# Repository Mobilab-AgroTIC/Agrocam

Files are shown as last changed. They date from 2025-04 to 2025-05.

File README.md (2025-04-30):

# Agrocam
L’Agrocam est un objet connecté à construire soi-même permettant de prendre des photo quotidiennement.

Ce système a été testé dans divers contextes, notamment pour suivre la croissance de la vigne, les opérations qui y sont menées (rognage, travail du sol, épamprage) … Des caméras sont maintenant aussi déployées sur d'autres cultures par des membres de la communauté en grande culture.

[Ce tutoriel](https://mobilab.agrotic.org/2025/02/18/agrocam/) vous guidera dans la fabrication d’une Agrocam. Le système est connecté via le réseau 3G/4G, ce qui permet de visualiser les photos directement sur Internet, avec une remontée tous les jours.

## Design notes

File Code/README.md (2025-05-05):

**Ce readme n'est plus maintenu à jour, pour suivre le tutoriel aller sur https://mobilab.agrotic.org/2025/02/18/agrocam/**
Ce Readme vous accompagne sur les étapes à accomplir pour paramétrer le Raspberry et la carte Witty Pi 4. 

Vous devriez avoir le matériel suivant : 



Pour commencez ce tutoriel et si vous souhaitez envoyer vos images sur agrocam.agroti.org afin de les visualiser vous devez déclarer votre Agrocam. Pour l'instant, il n'y a pas de procédure automatisée pour la déclaration de votre Agrocam. Il faudra donc envoyer un mail à basile.ploteau@supagro.fr en indiquant que vous souhaitez créer une Agrocam. Il vous renverra une chaine de 8 caractères qui sera le nom de votre Agrocam ainsi que le fichiers credentials.py utile dans la suite du tutoriel. Il faudra conserver ce nom car il sera utile à différents moments du tutoriel.

Ce Readme vous accompagne sur les étapes à accomplir pour paramétrer le Raspberry et l'Arduino promini 3,3 V. Le tutoriel est découpé en 3 grandes étapes : 

# 1. Préparer le dongle 4G
## 1.1. La carte SIM
Pour fonctionner de manière connectée l'Agrocam a besoin de connexion Wifi. Dans ce tutoriel vous suiverez des étapes qui permettent d'intégrer une clé 4G dans l'Agrocam qui produit directement un réseau Wifi. Pour fonctionner, cette clé 4G a besoin d'une carte SIM (les mêmes qu'il y a dans les téléphones). Un forfait de 5 Go/mois sera largement suffisant pour envoyer une photo par jour, il existe maintenant des forfaits abordables. Vous pouvez choisir de passer par n'importe quel opérateurs. Jusqu'à maintenant l'Agrocam a été testée avec les réseaux de Orange et de Bouygues.

## 1.2. Paramétrer le dongle 4G
Avant d'insérer la carte SIM dans le Dongle 4G, assurez vous d'avoir supprimé le code PIN. Pour retirer le code PIN de la carte SIM il faut insérer la carte dans un téléphone et se rendre dans les paramètres de ce dernier pour désactiver la sécurité.

Vous pouvez essayer d'insérer la carte SIM dans le Dongle 4G et de brancher la clé 4G à une alimentation USB. Ensuite connectez vous à votre clé 4G en wifi avec un ordinateur ou un smartphone (le nom de la clé (son SSID) et son mot de passe d'usine (souvent : "1234567890" sont indiqués sur le dos de la clé 4G). 
Vous devriez avoir accès à internet, faite une recherche sur Google pour vérifier que c'est bien le cas. Si tout fonctionne vous pouvez passer à la partie 2. Il est possible que malgré une carte SIM fonctionnelle la connection à internet ne se fasse pas. Cela est du à un problème d'APN mal configuré sur la clé 4G.
Pour modifier les paramètres d'APN vous devrez :

**3. Réaliser le montage électronique**

# 1. Programmer l'Agrocam 
## 1.1. Paramétrer le dongle 4G
Avant d'insérer la carte SIM dans le Dongle 4G, assurez vous d'avoir supprimer le code PIN. Pour retirer le code PIN de la carte SIM il faut insérer la carte dans un téléphone et se rendre dans les paramètres de ce dernier pour désactiver la sécurité.

- Vous connecter au réseau Wifi du dongle 4G avec votre PC
- Vous connecter à l'interface de paramétrage du dongle. Pour cela vous devez taper dans un navigateur quelconque l'adresse IP locale de votre Dongle. Elle est souvent indiquée au dos du Dongle et ressembe à quelque chose comme : 192.168.100.1
- Le dongle vous demande des identifiants, par défaut Username : "admin" et Password : "admin"



- Une fois connecté vous pouvez aller dans Advanced>APN Setting



- Vous cochez "profile 1" à la place de "default". Ensuite le remplissage du formulaire dépend de chaque opérateur. En général chez Orange il n'y a qu'un seul APN donc rarement des problèmes mais chez leur concurents il faut souvent tester différents APN. Voici les paramètres qui ont fonctionné pour une carte SIM Bouygues. Attention l'APN peut différer en fonction du forfait que vous avez pris.



- Une fois le formulaire créé cliquez sur "Save Configuration" puis "Execute"
- Attendez quelques secondes, ouvrez un nouvel onglet et faite une recherche pour vérifier si vous êtes bien connecté.

# 2. Préparer le Raspberry Pi Zero 
## 2.1. Initialiser le Raspberry Pi Zero
- Installer Raspberry Pi imager https://www.raspberrypi.com/software/
- Ouvrir Raspberry Pi imager
- Insérer la carte SD du raspberry dans le PC
- La fenêtre suivante s'affiche. Il faut passer dans les 3 menus pour préparer l'écriture de l'image sur le raspberry


1. Sélectionner le modèle du Raspberry **Raspberry pi zero**
2. Sélectionner l'OS **Raspberry Pi OS Lite (32-bit)**
3. Sélectionner l'espace de stockage correspondant à la carte SD

- Puis en cliquant sur **Suivant** un message demande si vous souhaitez modifier les paramètres. Cliquez sur **Modifier réglages**, une fenêtre s'ouvre:



- **Dans General** : Vous pouvez indiquer un nom d'utilisateur et un mot de passe pour votre Raspberry, vous pouvez conserver "pi" pour les deux. Vous pouvez aussi donner comme mot de passe la chaine de 8 caractères qui vous a été attribué lors de la déclaration de l'Agrocam sur le serveur, cela sécurisera votre raspberry s'il devait tomber entre de mauvaises mains.
- **Dans General** : Définir les paramètres Wifi (SSID, Password, pays (FR)) du dongle 4G. Bien penser à vérifier que le "pays Wifi" est en "FR"
- **Dans Service** : Activez le SSH et sélectionnez "utiliser un mot de passe pour l'authentification"



4. Cliquez sur **enregistrer** puis sur **Oui** puis une dernière fois sur **Oui**
5. L'écriture peut prendre du temps, n'hésitez pas à faire les installations de la partie 2.3 en attendant

## 2.2. Installer les logiciels pour la suite
- Installer [WinSCP](https://winscp.net/eng/download.php) sur votre PC. Ce logiciel permet de se connecter au raspberry en SSH, de parcourir ses fichier et d'interagir avec le terminal de commandes.
- Installer [Network analyzer](https://play.google.com/store/apps/details?id=net.techet.netanalyzerlite.an&hl=fr&gl=US) sur votre smartphone. Cette application permet de scaner un réseau wifi et de trouver les appareils (leur adresse IP) qui y sont connectés.

## 2.3. Réaliser les branchements
- Insérer la carte SD dans le raspberry
- Brancher la Picam. Attention au sens de branchement de la nappe de cable _(cf. photo ci-dessous)_. Attention les connecteurs sont fragiles, à manipuler avec précautions.


- Brancher le dongle 4G au Raspberry sur le port **"USB"** _cf. photo ci-dessous_ _Par la suite il est possible que le dongle se déconnecte de temps à autre, ce qui va poser problème. Cela est du au Raspberry qui en fonction des modèle de dongle 4G ne fournit pas une intensité suffisante. Si cela se présente, veuillez brancher le dongle sur une autre source de courant par exemple un chargeur rapide 2 ampères de téléphone portable_
- Brancher l'alimentation sur le port **"PWR IN"** _cf. photo ci-dessous_


## 2.4. Se connecter au Raspberry depuis un PC

- Connecter un smartphone au réseau du dongle 4G (avec SSID et mot de passe précédemment paramétrés)
- Avec l'application mobile Network Analyzer cliquer sur "Scan" et identifier l'adresse IP du raspberry Pi:


- Sur PC, ouvrir WinSCP et créer une nouvelle session de connexion au Raspberry . Saisir les informations suivantes : Protocole de fichier : **SFTP**; Nom d'hôte : **IP obtenue sur Network analyzer**; Nom d'utilisateur : **pi** (sauf changement); Mot de passe : **défini partie 2**
- Depuis WinSCP ouvrir Putty 
- Un terminal de commande s'ouvre et vous demande un mot de passe. Il s'agit toujours du même défini à la partie 2. Le mot de passe ne s'affiche pas mais appuyer sur "entrée" et ça marche. Attention, le Ctrl+V ne fonctionne pas sur le terminal de commande. Si vous souhaitez coller quelque chose, il faudra simplement faire un clic droit.

## 2.5. Installer les librairies 

```
sudo apt install python3-smbus
sudo apt install python3-picamera2
```
Par moment l'installation s'arrête pour vous demander si vous souhaitez continuer. Tapez "Y" puis "entrée" et l'installation continue.

## 2.6 Ajouter d'autres SSID (optionnel)
Pour l'instant vous ne pouvez accéder à votre raspberry qu'en vous connectant en SSH par l'intermédiaire du Dongle 4G. Cela est risqué car si le dongle ne fonctionne plus, vous ne pourrez plus accéder au raspberry. On vous recommande donc d'ajouter d'autres SSID (votre partage de connexion par exemple. Pour cela :
- ```nmcli device wifi list``` permet de visualiser les SSID disponibles
- ```nmcli device wifi connect "SSID" password "PASSWORD"```
- Attention lorsque le raspberry a réussi à se connecter à un autre wifi, votre terminal putty ne communique plus avec le raspberry car votre PC et le raspberry ne sont plus sur le même réseau. 
  
# 3 Ajouter les fichiers sur le raspberry pi
### 1.6.2 Installer WiringPi
```
git clone https://github.com/WiringPi/WiringPi.git
cd WiringPi
git pull origin
./build
cd ..
```
### 1.6.3 Installer pip et python-dotenv
Cela peut prendre un peu de temps 
```
sudo apt-get install python3-pip
pip install python-dotenv
sudo cp -R /home/pi/.local/lib/python3.9/site-packages/dotenv /usr/lib/python3.9 
```
*On déplace la librairie pour qu'elle soit trouvée en démarrage automatique*
## 1.7. Ajouter les fichiers sur le raspberry pi
Cette opération peut se faire depuis WinSCP en glissant et déposant les fichiers
## 3.1 Créer le répertoire pour les photo
```
sudo mkdir Agrocam
```
## 3.2 Choisir votre fréquence d'allumage
Vous avez normalement reçu un fichier "credentials.py" de la part de Basile Ploteau lorsque vous avez demandez la création de votre Agrocam. Ouvrez ce fichier avec n'importe quel editeur de text comme Notepad++ ou un simple bloc note. Il y a une liste qui s'appelle ```trigger_times``` et qui contient les heures (GMT) à laquelle vous souhaitez que l'Agrocam se déclenche. Par exemple ```trigger_times=[time(6,30,00),time(8,40,00),time(12,0,0)]``` déclenchera une acquisition de photo à 6:30:00, 8:40:00 et 12:00:00; ```trigger_times=[time(12,0,0)]``` déclenchera une acquisition de photo à 12:00:00.

## 3.3 Ajouter les fichiers
Depuis l'interface de WinSCP déplasser les fichiers suivants. Le fichier agrocam.py se trouve sur ce repertoire Github. Le fichier credentials.py vous a été envoyé par Basile Ploteau.
- Glisser déposer agrocam.py dans /home/pi
- Glisser déposer credentials.py dans /home/pi
Donner tous les droits au script _(première ligne ci-dessous)_ et effacer les "\r" et "r" de fin de ligne _(2e ligne ci-dessous, cela n'est pas toujours nécessaire mais ces caractère spéciaux on pu être ajouté si le script a été édité sur un outil Windows, Visual Studio Code par exemple)_
```
sudo chmod 777 Agrocam
sed -i -e 's/\r$//' agrocam.py
sed -i -e 's/\r$//' credentials.py
```
**NB :** Le script agrocam.py envoie la commande ```sudo shutdown -h now``` à la fin de son exécution ce qui éteint l'Agrocam. Pour débugger le script (c'est-à-dire reprendre la main dessus) il est recommandé de commenter cette ligne _cf. partie 7_

# 4. Programmer l'allumage de l'Agrocam avec la carte WittyPi
## 4.1 Installer WittyPi
Installer WittyPi avec les lignes de commandes suivantes.
```
wget http://www.uugear.com/repo/WittyPi4/install.sh
sudo sh install.sh
```
Puis éteindre le raspberry avec ```sudo shutdown -h now```. Attendre que la LED verte s'eteigne définitivement puis débrancher l'alimentation électrique. 

## 4.2 Connecter la carte WittyPi 4 au Raspberry
Insérer une pile 3V (si possible rechargeable et fourni avec la carte WittyPi 3) dans l'emplacement prévu à cette effet sur la carte Witty Pi

Les broches s'emboitent de la manière suivante.



## 4.3 Paramétrer le WittyPi
Brancher l'alimentation électrique directement sur la carte Witty Pi 4 (l'alimentation du raspberry a été débranché en 4.1), c'est cette carte qui va ensuite gérer l'alimentation du raspberry. Pour que le raspberry démarre (en attendant qu'on lui donne un planing de mise en route), il faut appuyer sur le bouton poussoir de la carte Witty Pi. Lors de cette première mise en route, il est possible que le Dongle 4G ne s'allume pas. Il suffit de le débrancher et rebrancher.



Se connecter au Raspberry comme dans la partie 2.4, ouvrir le terminal de commande et démarrer WittyPi avec la commande suivante :
Depuis WinSCP, glisser déposer .env dans ```/home/pi``` une fois modifié avec les informations pertinentes entre les "" (hostname,user,password). Ce fichier contient les informations d'authentification pour accéder au serveur FTP sur lequel les photos seront sauvegardées. Attention le fichier peut être caché

Le fichier peut aussi être crée depuis le terminal :
```
touch .env
sudo nano .env
```
Contenu de .env
```
hostname = ""
user = ""
password =""
```

## 1.8. Démarrer la script au reboot
Cette partie permet de démarrer le script ```Agrocam_raspberry.sh``` au démarrage. Attention, le script éteint le raspberry à la fin de son exécution. Cette extinction n'a pas lieu si ```controlPin==1```, il faut donc brancher le GPIO 24 au 3,3v pour que l'Agrocam reste allumée _cf. partie 1.10._

Ouvrir le crontab 
```
sudo crontab -e
```
Puis sélectionner ```1. /bin/nano``` en tapant ```1```
Ajouter une ligne à la fin du crontab :
```
@reboot sudo /home/pi/Agrocam_raspberry.sh 
```
Ajouter ```>> /var/log/Agrocam.log 2>&1``` à la ligne précédente pour créer un fichier de log pour débugger

## 1.9. Tester le script
Pour relancer le raspberry : ```sudo reboot```, il devrait s'allumer, actionner le servomoteur, prendre une photo, réactionner le servomoteur, envoyer la photo sur le serveur et enfin s'éteindre.

## 1.10. Debugger l'Agrocam
Le script ```Agrocam_raspberry.sh``` éteint l'Agrocam à la fin de son exécution, une fois cette partie 1 terminée il serait donc impossible de se connecter au raspberry en SSH car le script ```Agrocam_raspberry.sh``` est lancé à chaque démarrage _(cf. partie 1.8)_. La solution consiste donc à empêcher que le script n'aille jusqu'au bout lorsqu'on le désire. Pour celà il y a une boucle en python à la fin du script qui tourne indéfiniement si le port GPIO 24 est "TRUE" donc connecté au 3,3V **(à l'aide du cavalier)**:
```
import time
import RPi.GPIO as GPIO
controlPin=24
GPIO.setmode(GPIO.BCM)
GPIO.setup(controlPin, GPIO.IN)
i=1
while (GPIO.input(controlPin) == 1) :
	time.sleep(5)
	print("ControlPin is not LOW. i = ", i)
	i += 1
```

# 2. Programmer l'allumage de l'Agrocam
On va se servir d'un arduino mini pour alimenter le Raspberry à intervalles régulier (et donc prendre une photo). L'arduino active un transistor qui lui même connecte le raspberry à une power bank _(cf. schéma en partie 3)_ 
- Installer le logiciel [Arduino](https://www.arduino.cc/en/software)
## 2.1 Brancher l'Arduino au PC
- Utiliser un FTDI pour relier l'Arduino mini au PC. S'il s'agit d'un Arduino mini 3,3 V penser à ce que le FTDI soit sur la position 3,3V (boutou ou cavalier selon les modèles)


- Attention au sens de branchement du FTDI, les broches VCC, GND doivent coïncider. De même RX doit être branché sur TX et inversement :


- Dans le logiciel Arduino, dans ```Outil > Type de carte``` sélectionner la carte **"Arduino Pro or Pro Mini"**
- Puis sélectionner le port qui s'est ajouté à la liste en branchant le cable USB (celui relié au FTDI) à l'ordinateur, dans ```Outil > Port```


## 2.2 Téléverser le script 
- Depuis Github copier le script Agrocam_arduino.ino et le coller dans le logiciel Arduino.
- Sauvegarder et téléverser le script :

## 2.3 Modifier la fréquence d'acquisition d'image
Par défaut le script va lancer l'allumage approximativement toutes les 8h mais il est possible de modifier cette durée. Pour cela :
- ouvrir le script
- Trouver la boucle :
```
for (int i = 1; i <3600 ; i++){ //3600 pour 8h, 3150 avec le recalage
      LowPower.powerDown(SLEEP_8S, ADC_OFF, BOD_OFF);
  }
```
Une liste de paramètre et de fonctionnalités s'affichent. Dans l'ordre nous allons procéder ainsi :
1. ```3.Synchronize time``` taper 3 et entrer
2. ```7. Set low voltage threshold``` taper 7 et entrer puis saisir 7V et entrer
3. ```8. Set recovery voltage threshold``` taper 8 et entrer puis saisir 0 et entrer (sinon quand on change la batterie la camera pourrait redemarrer)
4. ```11. View/change other settings...``` taper 11 et entrer. Ensuite suivre les instructions pour chaque paramètre. Attention lorsqu'un paramètre est validé on revient au menu initial, il faut donc revenir dans ```11. View/change other settings...```

| Paramètre  | Valeur |
| --- | --- |
| Default state when powered  | OFF  |
| Power cut delay after shutdown  | Inchangé  |
| Pulsing interval during sleep  | 20 |
| White LED duration  | 0  |
| Dummy load duration  | 0  |
| Vin adjustment | Inchangé  |
| Vout adjustment  | Inchangé  |
| Iout adjustment  | Inchangé  |

6. ```13. Exit``` taper 13 et entrer

# 5 Démarrer le script au reboot avec systemd
Pour l'instant, si vous éteignez et rallumez votre raspberry il ne se passera rien. Pour que l'Agrocam prenne une photo lorsqu'elle démarre, il faut le lui indiquer en suivant ces étapes.
```
sudo nano /lib/systemd/system/agrocam.service
```

Le fichier agrocam.service s'ouvre, pour l'instant il est vide. Il faut donc coller ce qui suit dedans :

```
[Unit]
Description=My Script Service
After=multi-user.target

[Service]
Type=idle
ExecStart=/usr/bin/python3 /home/pi/agrocam.py > /home/pi/myscript.log 2>&1
WorkingDirectory=/home/pi
User=pi
ExecStartPre=/bin/sleep 10

[Install]
WantedBy=multi-user.target
```

Puis on quitte le mode édition avec Ctrl+X puis on accepte en tapant "y" puis "entrée"

```
sudo chmod 644 /lib/systemd/system/agrocam.service

sudo systemctl daemon-reload
sudo systemctl enable agrocam.service
```

Si vous souhaitez savoir quel est l'état de votre service :
```
sudo systemctl status agrocam.service
```
Enfin éteindre l'Agrocam avec : ```sudo shutdown -h now```

# 6 Finaliser les branchements
- Brancher le servo moteur sur les broches du WittyPi. Le fil rouge du servo est relié à une **broche 5V**, le fil noir à une **broche GND**, et le fil restant (blanc, jaune) à la **broche GPIO 18** _cf.figures ci-dessous_
- Connecter les **broches GPIO 24 et GND** à l'aide d'un [cavalier](https://fr.rs-online.com/web/p/cavaliers-et-shunts/2518682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)_(cf.figures ci-dessous_). Dans cette position l'Agrocam fonctionnera normalement, c'est à dire qu'elle s'éteindra après avoir pris une photo. Pour empêcher cela on peut basculer le cavalier entre la **broche 3,3V** et la **broche GPIO 24** ainsi l'Agrocam ne s'éteint pas et il est possible d'en prendre le contrôle (partie 7).

   

# 7 Demarrer l'Agrocam
## 7.1 Passer sur l'alimentation batterie
Insérer deux cellules Lithium 3,7V dans le boitier de pile et connecter le boitier à l'aide d'un connecteur JST à la carte WittyPi (Attention à la polarité). Si votre boitier n'a pas de connecteur (uniquement des fils dénudés), de nombreuses ressources sont disponibles en ligne ou dans le Fablab le plus proche de chez vous pour apprendre à faire ces connectiques.

Voici le montage que vous devriez obtenir



## 7.2 Relancer l'Agrocam
Pour relancer l'Agrocam, appuyer sur le bouton poussoir : elle devrait s'allumer, actionner le servomoteur, prendre une photo, réactionner le servomoteur, envoyer la photo sur le serveur et enfin s'éteindre.

# 8 Debugger l'Agrocam
Le script ```agrocam.py``` éteint l'Agrocam à la fin de son exécution, une fois cette partie 1 terminée il serait donc impossible de se connecter au raspberry en SSH car le script ```agrocam.py``` est lancé à chaque démarrage _(cf. partie 1.8)_. La solution consiste donc à empêcher que le script n'aille jusqu'au bout lorsqu'on le désire. Pour celà il y a une boucle en python à la fin du script qui tourne indéfiniement si le port GPIO 24 est "TRUE" donc connecté au 3,3V **(à l'aide du cavalier)**:
```
i=1
while (GPIO.input(controlPin) == 1) :
	time.sleep(5)
	print("ControlPin is not LOW. i = ", i)
	i += 1
```
Ci-dessous la position du cavalier pour que le script n'éteigne pas l'Agrocam à la fin de son exécution :


## 2.4 Tester l'Agrocam
Une fois ces étapes terminées. Eteindre l'Agrocam ```sudo shutdown -h now ``` puis repositionner le cavalier en position initiale.
Vous pouvez débrancher l'alimentation et connecter les cellules Li-ion comme sur la photo ci-dessous. Cette [vidéo](https://www.youtube.com/watch?v=nqwYTafg8Z0) vous explique comment réaliser la connectique mâle du XH2.54 sur les fils du boitier d'alimentation.

- Modifier 3600 par une autre valeur. La boucle permet de mettre l'Arduino en sommeil pour 8 secondes, la durée totale sera donc un multiple de 8 secondes.
- Téléverser une fois le script modifié

# 3. Réaliser le montage électronique
L'objectif de cette partie est de modifier l'arrivée de courant du Raspberry pour que celle-ci soit contrôlée par l'Arduino Mini par l'intermédiaire du transistor IRLZ44N.
## 3.1 Cablage sur la breadboard
L'objectif est d'obtenir le câblage comme sur la photo ci-dessous. Il faut le matériel suivant : des headers 3 paires de 2, des jumpers de tailles différentes, un transistor IRLZ44N et une résistance de 20 MΩ (Cette résistance peut être inférieure mais dans notre cas cela fonctionne bien comme ça). Attention à bien orienter le transistor. Pour les plus connaisseurs le transistor est cablé de la manière suivante :
- La gate est connectée au port 2 de l'Arduino
- Le drain est connecté à la masse du câble d'alimentation côté Raspberry
- La source est connecté à la masse du câble d'alimentation côté Powerbank


## 3.2 Cablage des alimentations
Une fois la breadboard assemblée, connecter les alimentations et le raspberry pi de la manière suivante.


Pour effectuer l'alimentation du Raspberry il faut sectionner le cable USB d'alimentation pour accéder aux câbles d'alimentation (rouge et noir).
Pour brancher les câbles d'alimentation sur la breadboard il faut sertir des connecteurs JST femelle dessus, denombreux tutoriel sont disponibles en ligne pour apprendre à réaliser ces sertissages.

Le câblage final ressemble à ceci : 

Enfin pour tester le cadrage vous pouvez appuyer à n'importe quel moment sur le bouton poussoir de la Witty Pi 4 pour faire une photo. La caméra démarrera automatiquement à l'heure prédéfinie.



La partie fonctionnelle de l'Agrocam est terminée. Il reste à faire le montage dont le tutoriel se situe [ici](https://github.com/Mobilab-AgroTIC/Agrocam/blob/main/3D%20files/README.md)

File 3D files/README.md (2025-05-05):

Tous les fichiers pour assembler une Agrocam sont disponibles ici

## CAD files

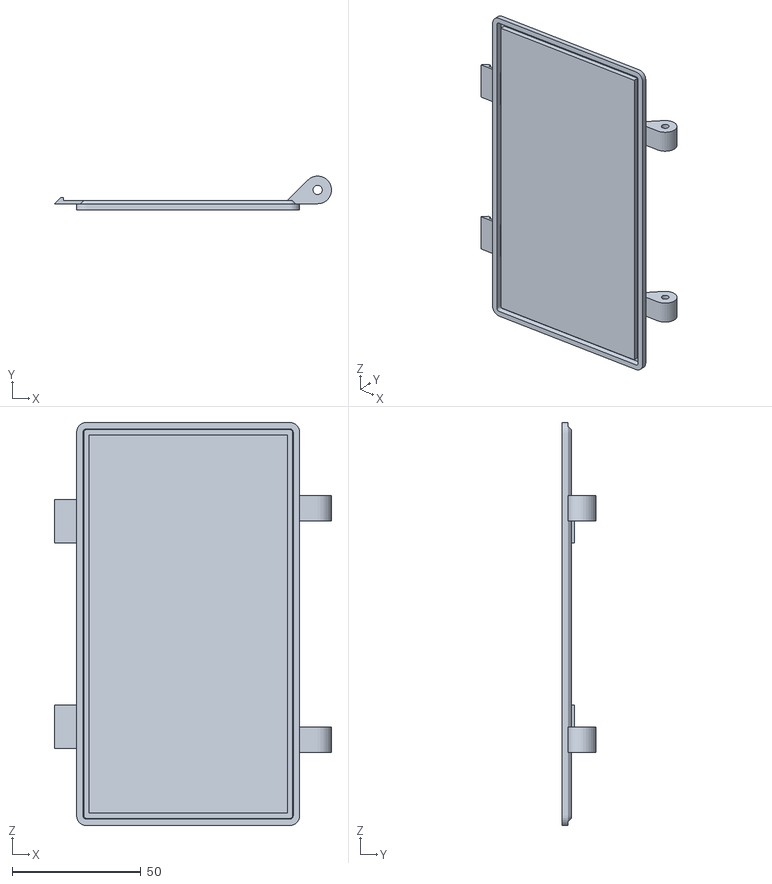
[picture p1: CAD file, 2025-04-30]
3D files/couvercle.stl
107.8 x 13.2 x 156.8

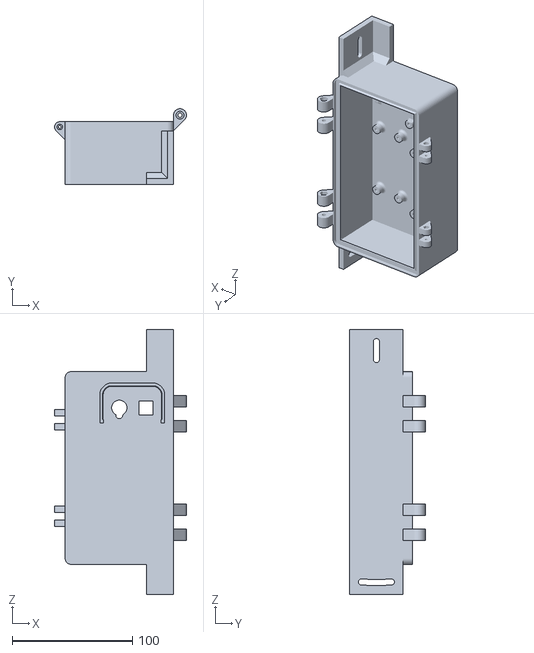
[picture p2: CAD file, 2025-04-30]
3D files/Boitier.stl
109.6 x 62.8 x 220.0

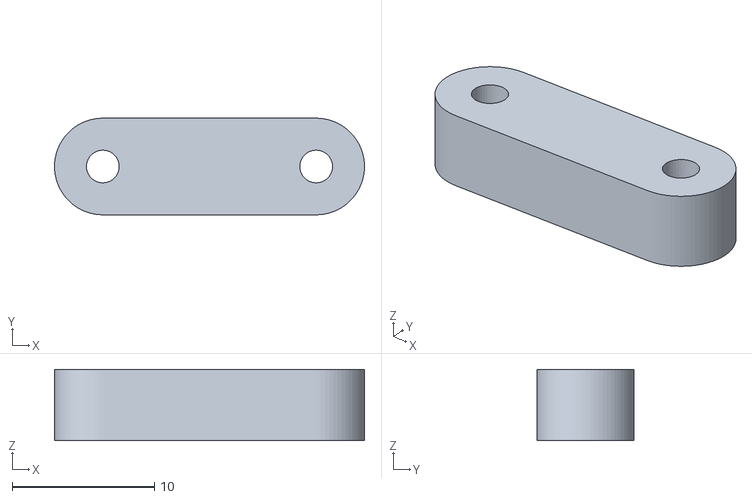
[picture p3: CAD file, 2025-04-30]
3D files/Axe_loquet.stl
21.8 x 6.80 x 5.00

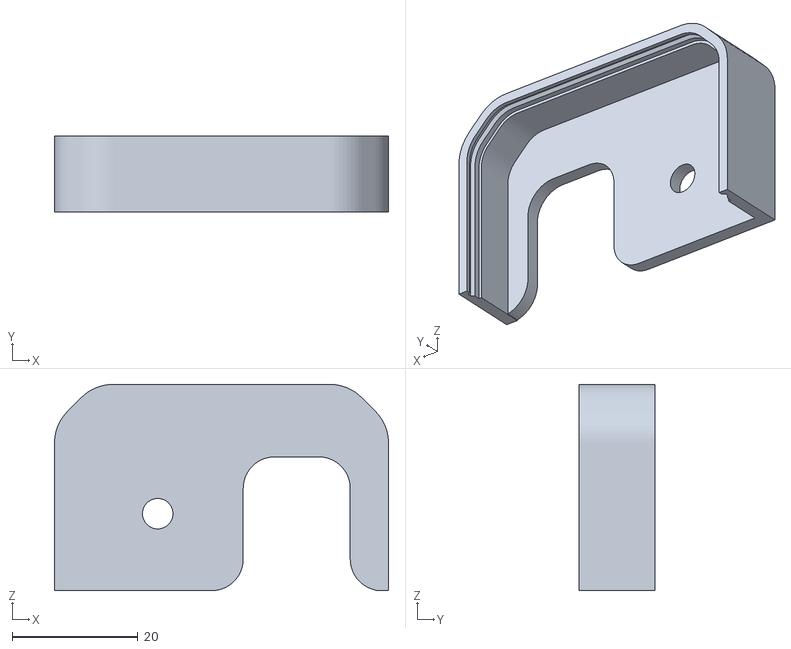
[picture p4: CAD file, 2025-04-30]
3D files/casquette.stl
53.2 x 12.1 x 32.8

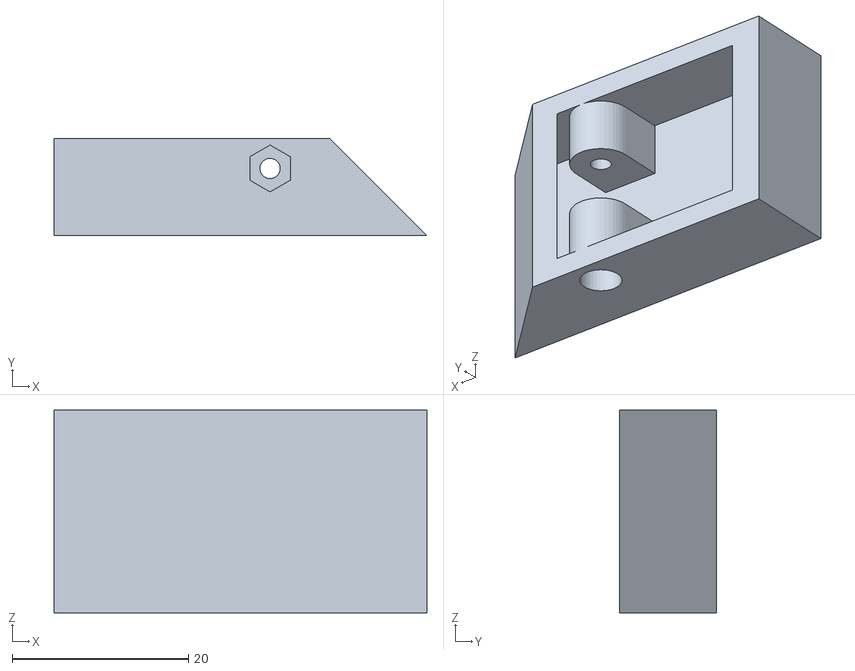
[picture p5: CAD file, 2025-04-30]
3D files/Levier_loquet.stl
42.3 x 11.0 x 23.0

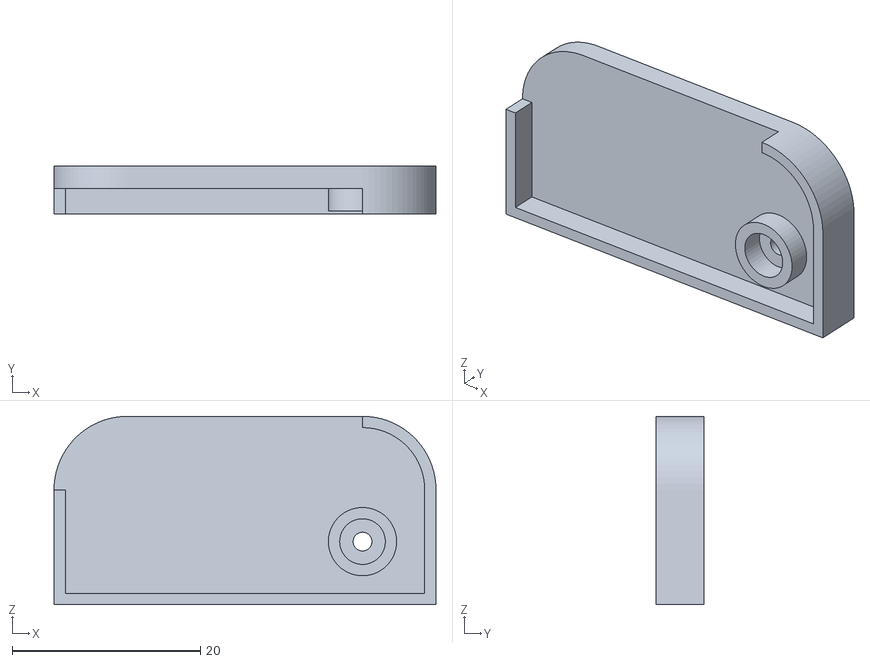
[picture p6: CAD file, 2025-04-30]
3D files/obturateur.stl
40.5 x 5.10 x 20.0

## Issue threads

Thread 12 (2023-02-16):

User story : Première installation grâce à un interrupteur

basileploteau, 2023-02-16:
# Contexte
Actuellement dans la version Agrocam-WittyPi, l'utilisateur doit appuyer sur un bouton poussoir pour prendre une première photo s'il veut vérifier son cadre. Cela n'est pas pratique car demande d'ouvrir le boitier et de le refermer suffisamment vite pour le remettre en position de prise de photo.
# Solution
- Sur le câble 5V de l'alimentation de la batterie, positionner un interrupteur à levier I/O qui sera déporté à l'extérieur du boitier.
- Modifier le paramétrage de la carte WittyPi dans *"View/change other settings..."* puis *"Default state when powered"* en définissant la valeur par défaut sur 0 (correspondant à 'ON')

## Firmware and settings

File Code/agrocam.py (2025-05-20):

#!/usr/bin python3
import RPi.GPIO as GPIO
from gpiozero import Servo
from picamera2 import Picamera2, Preview
# from libcamera import Transform
from time import sleep
from ftplib import FTP
import requests
from datetime import datetime, timedelta, timezone
import subprocess
import credentials as credentials
import sys

# Numéro de la broche GPIO à utiliser pour le servo moteur
pwm_gpio = 18

# Numéro de la broche de debogage
controlPin = 24

# Configuration de la caméra
camera = Picamera2()

# Configuration for rotating picture
# Ci-dessous d'anciennes config qui ne minimise la taille des images (<500 ko)
# camera_config = camera.create_still_configuration(main={"size": (1920, 1080)}, lores={"size": (640, 480)}, display="main",transform=Transform(180))
camera_config = camera.create_still_configuration(main={"size": (4608, 2592)}, lores={"size": (640, 480)}, display="main")
# La config ci-dessous maximise la taille et donc la qualité de l'image
camera.configure(camera_config)

camera.set_controls({"AfMode": 2}) #Autofocus  
#camera.set_controls({"LensPosition": 2.0})
# Configuration du servo
frequence = 50

def initialize_GPIO() :
    GPIO.setmode(GPIO.BCM)
    GPIO.setup(pwm_gpio, GPIO.OUT)
    GPIO.setup(controlPin, GPIO.IN)

def angle_to_percent (angle) :
    if angle > 180 or angle < 0 :
        return False
    start = 4
    end = 12.5
    ratio = (end - start)/180 #Calcul ratio from angle to percent

    angle_as_percent = angle * ratio

    return start + angle_as_percent

def prendre_photo(date):
    camera.start_preview()
    camera.start() 
     
    sleep(1)
    camera.capture_file('/home/pi/Agrocam/photo'+date+'.png')
    camera.stop_preview()
    camera.close()

def envoyer_http(date_for_filename_part):
    # URL of the API endpoint
    url = f'https://agrocam.agrotic-dev.org/api/upload'

    now = datetime.now()

    # ISO 8601 format for reliable API date parsing
    now_utc = datetime.now(timezone.utc)
    date_for_api = now_utc.isoformat(timespec='seconds')

    # --- Get Voltage from Wittypi script ---
    voltage = None
    formatted_voltage_for_filename = "unknown_voltage"
    try:
        command = subprocess.run(
            ['bash', '-c', 'source /home/pi/wittypi/utilities.sh && get_input_voltage'],
            capture_output=True,
            text=True,
            check=True
        )
        voltage_str = command.stdout.strip()
        voltage = float(voltage_str)
        # Format voltage for filename (replace '.' with '_')
        formatted_voltage_for_filename = voltage_str.replace('.', '_')
        print(f"Successfully obtained voltage: {voltage} V")

    except FileNotFoundError:
        print(f"Error: 'bash' command not found. {sys.exc_info()[0]}", file=sys.stderr)
    except subprocess.CalledProcessError as e:
        print(f"Error running get_input_voltage script: {e}", file=sys.stderr)
        print(f"Stderr:\n{e.stderr}", file=sys.stderr)
    except ValueError:
        print(f"Error converting voltage reading '{voltage_str}' to float. Received unexpected output.", file=sys.stderr)
    except Exception as e:
         print(f"An unexpected error occurred while getting voltage: {e}", file=sys.stderr)
    # ---------------------------------------

    # Construct the full path for the photo file to read
    image_path = f'/home/pi/Agrocam/photo{date_for_filename_part}.png'

    # Define the key used in metadata and filename
    metadata_key = credentials.name # Replace with actual key variable if dynamic

    # Construct the desired filename for the upload, including key, date, and voltage
    upload_filename = f"{metadata_key}_{date_for_filename_part}_{formatted_voltage_for_filename}.png"

    # Populate metadata
    metadata = {
        'key': metadata_key,
        'power_level': voltage, # Use the float voltage (will be None if conversion failed)
        'date_acquisition': date_for_api,
    }

    try:
         # Open the image file and prepare for upload
         with open(image_path, 'rb') as f:
             # 'files' dictionary format: {'field_name': ('filename_for_server', file_object, 'content_type')}
             files = {'photo': (upload_filename, f, 'image/png')}
             data = metadata # Metadata is sent as form fields

             print(f"Sending data via HTTP POST...")

             response = requests.post(url, files=files, data=data)

         if response.status_code == 200:
             print("Photo and metadata sent successfully! Status:", response.status_code)
         else:
             print(f"Error sending data. Status code: {response.status_code}", file=sys.stderr)
             print("Response body:", response.text, file=sys.stderr)

    except FileNotFoundError:
         print(f"Error: Image file not found at {image_path}.", file=sys.stderr)
    except requests.exceptions.RequestException as e:
        print(f"HTTP request failed: {e}", file=sys.stderr)
    except Exception as e:
         print(f"An unexpected error occurred during HTTP request or file handling: {e}", file=sys.stderr)

def envoyer_sur_ftp(date):
    ftp = FTP(credentials.ftp_server)
    ftp.login(credentials.ftp_username, credentials.ftp_password)
    
    command = subprocess.run(['bash', '-c', 'source /home/pi/wittypi/utilities.sh && get_input_voltage'],capture_output=True,text=True)
    voltage = command.stdout.strip()
    with open('/home/pi/Agrocam/photo'+date+'.png', 'rb') as fichier:
        ftp.storbinary('STOR /data/'+ credentials.name +'/'+credentials.name+'_'  + date + '_' + voltage + '.png',fichier)
    ftp.quit()
    cmd="sudo mv /home/pi/Agrocam/photo"+date+".png /home/pi/Agrocam/"+credentials.name+"_"  + date + "_" + voltage + ".png"
    subprocess.run(['bash', '-c', cmd],capture_output=True,text=True)

def set_startup_time(date, hour, minute, second):
    command_set_startup = f"sudo bash -c 'source /home/pi/wittypi/utilities.sh && set_startup_time {date} {hour} {minute} {second}'"    
    command_net_to_system = subprocess.run(['bash', '-c', 'source /home/pi/wittypi/utilities.sh && net_to_system'],capture_output=True,text=True)
    command_system_to_rtc = subprocess.run(['bash', '-c', 'source /home/pi/wittypi/utilities.sh && system_to_rtc'],capture_output=True,text=True)
    subprocess.run(['bash', '-c',command_set_startup ],capture_output=True,text=True)
    
    print(command_set_startup)

def calculate_next_startup_time(trigger_times):
    now = datetime.now()
    today = now.date()

    # Créer des objets datetime pour chaque heure de déclenchement aujourd'hui
    trigger_datetimes_today = [datetime.combine(today, t) for t in trigger_times]

    # Filtrer pour trouver les déclenchements encore à venir aujourd'hui
    upcoming_triggers = [t for t in trigger_datetimes_today if t > now]

    # Si un déclenchement est encore à venir aujourd'hui, prendre le prochain ; sinon, prendre le premier de demain
    if upcoming_triggers:
        next_startup = upcoming_triggers[0]
    else:
        # Si tous les déclenchements sont passés pour aujourd'hui, prendre le premier déclenchement de demain
        next_startup = trigger_datetimes_today[0] + timedelta(days=1)

    # Extraire les valeurs pour `date`, `hour`, `minute`, `second`
    day = next_startup.day
    hour = next_startup.hour
    minute = next_startup.minute
    second = next_startup.second

    return day, hour, minute, second
    
def setup_wittypi():
    pulsing_interval = 13
    white_led_duration=7
    recovery_voltage=20
    threshold_voltage=70
    cmd_pulse = f"""sudo bash -c 'I2C_BUS=1;  source /home/pi/wittypi/utilities.sh  && i2c_write $I2C_BUS $I2C_MC_ADDRESS $I2C_CONF_PULSE_INTERVAL {credentials.pulsing_interval}'"""
    cmd_led = f"""sudo bash -c '  I2C_BUS=1; source /home/pi/wittypi/utilities.sh  && i2c_write $I2C_BUS $I2C_MC_ADDRESS $I2C_CONF_BLINK_LED {credentials.white_led_duration}'"""
    cmd_recovery_voltage=f"""sudo bash -c '  I2C_BUS=1; source /home/pi/wittypi/utilities.sh  && i2c_write $I2C_BUS $I2C_MC_ADDRESS  $I2C_CONF_RECOVERY_VOLTAGE {credentials.recovery_voltage}'"""
    cmd_threshold_voltage = f"""sudo bash -c '  I2C_BUS=1; source /home/pi/wittypi/utilities.sh  && i2c_write $I2C_BUS $I2C_MC_ADDRESS $I2C_CONF_LOW_VOLTAGE {credentials.threshold_voltage}'"""

    subprocess.run(cmd_led, shell=True, capture_output=True, text=True)
    subprocess.run(cmd_pulse, shell=True, capture_output=True, text=True)
    subprocess.run(cmd_recovery_voltage, shell=True, capture_output=True, text=True)
    subprocess.run(cmd_threshold_voltage, shell=True, capture_output=True, text=True)


def main():
    setup_wittypi()
    #sleep(30) # waiting for wifi
    initialize_GPIO()
    pwm = GPIO.PWM(pwm_gpio,frequence)
    pwm.start(0)
    now = datetime.now()
    current_date = now.strftime("%Y-%m-%d_%H%M%S")
    try:
        pwm.ChangeDutyCycle(angle_to_percent(0))
        sleep(0.2)
        pwm.ChangeDutyCycle(0)
        sleep(0.1)
        prendre_photo(current_date)
        print("photo prise")
        pwm.ChangeDutyCycle(angle_to_percent(90))
        sleep(0.2)
        pwm.ChangeDutyCycle(0)
        sleep(0.1)
        #envoyer_http(current_date)
        envoyer_sur_ftp(current_date)
        print("Envoi sur FTP terminé")
        sleep(1)  # Attendre avant de répéter le traitement

    except KeyboardInterrupt:
        pass

    finally:
        pwm.stop()
        camera.close()
        # Calcul de la prochaine date de déclenchement et enregistrement dans Wittypi
        day, hour, minute, second = calculate_next_startup_time(credentials.trigger_times)
        set_startup_time(day, hour, minute, second)
        i=1
        while (GPIO.input(controlPin) == 1) :
            sleep(5)
            print("ControlPin is not LOW. i = ", i)
            i += 1
        GPIO.cleanup()
        subprocess.run(['sudo', 'shutdown', '-h', 'now'])

if __name__ == "__main__":
    main()

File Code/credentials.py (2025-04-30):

from datetime import time
ftp_server = "agrocam.agrotic.org"
ftp_username = "user@agrotic.org"
ftp_password = "password"
name= "8_char_id"
trigger_times=[time(6,30,00),time(8,40,00),time(12,0,0)]
pulsing_interval = 20
white_led_duration=0
recovery_voltage=0
threshold_voltage=70

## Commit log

2021-11-16 First commit
    ajout des script Arduino & Raspberry
    Ajoute des fichiers 3D
    [boitier.stl, capot.stl]
2022-02-08 Ajout d'un fichier de configuration id.py dans lequel sont stocké les accès FTP
2022-02-08 ajout du fichier id_exemple.py pour la structure du fichier id.py
2022-02-15 Ajout d'un fichier .env contenant les crédentials FTP
2022-02-15 ajout d'un agrotic.env ignoré de git et contenant les credentials agrotic
2022-02-15 modif de .env
2022-02-15 Changement de l'adresse finale du module dotenv
2022-02-16 Déplacement code de agricam -> agricam/code
2022-03-01 delay adruino de 3150 à 3600
2022-03-08 add 3d files
    [9GSupport.stl, Boitier.stl, cameraSupport.stl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]
2022-04-13 Readme code jusqu'à installation des librairies
2022-04-13 Ajout section Arduino
2022-04-13 Modification pour Readme général
    Suppression des informations relativex au raspberry car elles sont présentes dans Agrocam/Code/Readme.md
2022-04-15 Ajouter la procédure de paramétrage du dongle 4G
2022-04-15 Correction mineur, port jumper et ' au lieu de "
2022-04-15 ajout de agrotic.env au gitignore
2022-05-19 Première mise à jour avec retours de Célia
2022-05-20 Mise à jour de la partie 3
2022-05-24 Fin du tuto raspberry
    Reste à faire le tuto arduino et le montage électronique
2022-05-24 Fin du tuto Arduino
    Reste à faire le tuto montage électronique
2022-06-22 Début des ajouts pour le cablage de l'arduino
2022-07-05 Ajout de remarque sur le paramétrage dongle 4G
2022-09-14 Ajouts de photos et corrections
2022-10-19 Changement de chronologie pour installer wittypi
2022-10-21 Inversement chronologie tutoriel
    En installant WittyPi avant de téléverser le script Agrocam_rasperry.sh on évite les bugs lié à la partie de lecture de tension dans la partie python qui ne reconnait pas de bus I2C avant que la carte wittypi ne soit connectée
2022-10-24 Ajout "activer bus I2C" pour smbus
2022-10-24 Ajout variable I2CAdress
2022-10-24 Recherche adresse I2C dans le fichier .env
2023-04-28 pas besoin de remotegpio
2024-03-21 upd servo ft90B
2024-08-23 synchronisation automatique de l'horloge avec le réseau
2025-02-13 Mise à jour .stl
    [9GSupport.stl, Axe_loquet.stl, Boitier.stl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]
2025-02-13 maj boitier
    [Boitier.stl]
2025-03-28 Replace .png by .jpg
    [agrocam.py]
2026-03-13 Rajout de la localisation qui avait disparu et choix de l'extension
2026-06-05 Add servo control functionality and update README
    - Introduced ServoManager class for managing servo motors.
    - Updated credentials.json to include GPIO pin configurations for servos.
    - Added new endpoint in credentials_web.py to test servo activation.
    - Enhanced README with instructions for creating a persistent hotspot.
    - Cleaned up agrocam.py by removing unused servo functions.
2026-11-04 Ajout des notes de version v2.1.0
2026-11-04 Complète les notes de version v2.1.0 et ignore les fichiers .pyc
2026-11-04 Ajout d'un aperçu caméra en direct à la page de maintenance
    Le flux MJPEG de rpicam-vid s'affiche dans la page de configuration.
    L'obturateur s'ouvre au démarrage de l'aperçu et se referme à son arrêt,
    y compris lorsque la page est quittée ou rechargée.
